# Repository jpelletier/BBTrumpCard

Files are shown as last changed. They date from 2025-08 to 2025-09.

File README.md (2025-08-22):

The Big Beautiful Trump Card is a clone of Steve Ciarcia's Trump Card based on the Zilog Z8001 CPU.
The project is released under OSHW.

To simplify the project, I use more recent components such as a CPLD to contain the glue logic and a memory chip to replace the dynamic memory.
The project is in the prototype stage for now. The PCB is at version 1, but untested yet.

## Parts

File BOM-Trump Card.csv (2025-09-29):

Reference | Value | Qty | MPN | PACKAGE | SUPPLIER | Description | Manufacturer | Supplier2 Part Number | Supplier Part Number | SUPPLIER2
C1,C4,C7,C10,C13 | 1µF | 5 |  | 0805 |  | Unpolarized capacitor
C2,C3,C5,C6,C8,C9,C11,C12,C14,C15,C16,C17,C19,C20,C22,C23 | 100nF | 16 |  | 0603 |  | Unpolarized capacitor
C18,C21,C24 | 10µF | 3 |  | 0805 |  | Unpolarized capacitor
J1 | Conn_02x05_Odd_Even | 1 |  |  | Digikey, AliExpress, eBay | Generic connector, double row, 02x05, odd/even pin numbering scheme (row 1 odd numbers, row 2 even numbers), script generated (kicad-library-utils/schlib/autogen/connector/)
R1,R2,R3,R4,R5,R6,R7,R8,R9,R10,R11,R12,R13,R14,R15,R16,R17,R18,R19,R20,R21,R22,R23,R24,R26,R27,R28,R29,R30,R31,R32,R33 | 10k | 32 |  | 0603 |  | Resistor, US symbol
R25 | 22 | 1 |  | 0603 |  | Resistor, US symbol
U1 | Z8001P | 1 |  | DIP-48 | eBay | CPU
U2 | CY62157ELL-45ZSXI | 1 |  | TSOP-II-44 | Digikey |  | Infineon | 2767919 | 448-CY62157ELL-45ZSXI-ND | Farnell UK
U3 | EPM7128STC100-15 | 1 | EPM7128STC100-15 | 1100-TQFP | AliExpress, eBay |  | Altera/Intel
U4 | 6116 | 1 |  | DIP-24 | eBay, AliExpress
U5,U6 | 74LS373 | 2 |  | DIP-20 | Digikey, AliExpress, eBay | 8-bit Latch, 3-state outputs
U7,U8 | 2716 | 2 |  | DIP-24 | -- valeurs mixées --
U9 | Z8581 | 1 |  | DIP-18 | AliExpress, eBay
U12,U13 | 74LS245 | 2 |  | DIP-20 | Digikey, AliExpress, eBay | Octal BUS Transceivers, 3-State outputs
Y1 | 12 MHz | 1 |  | HC49-U | Digikey, AliExpress | Two pin crystal

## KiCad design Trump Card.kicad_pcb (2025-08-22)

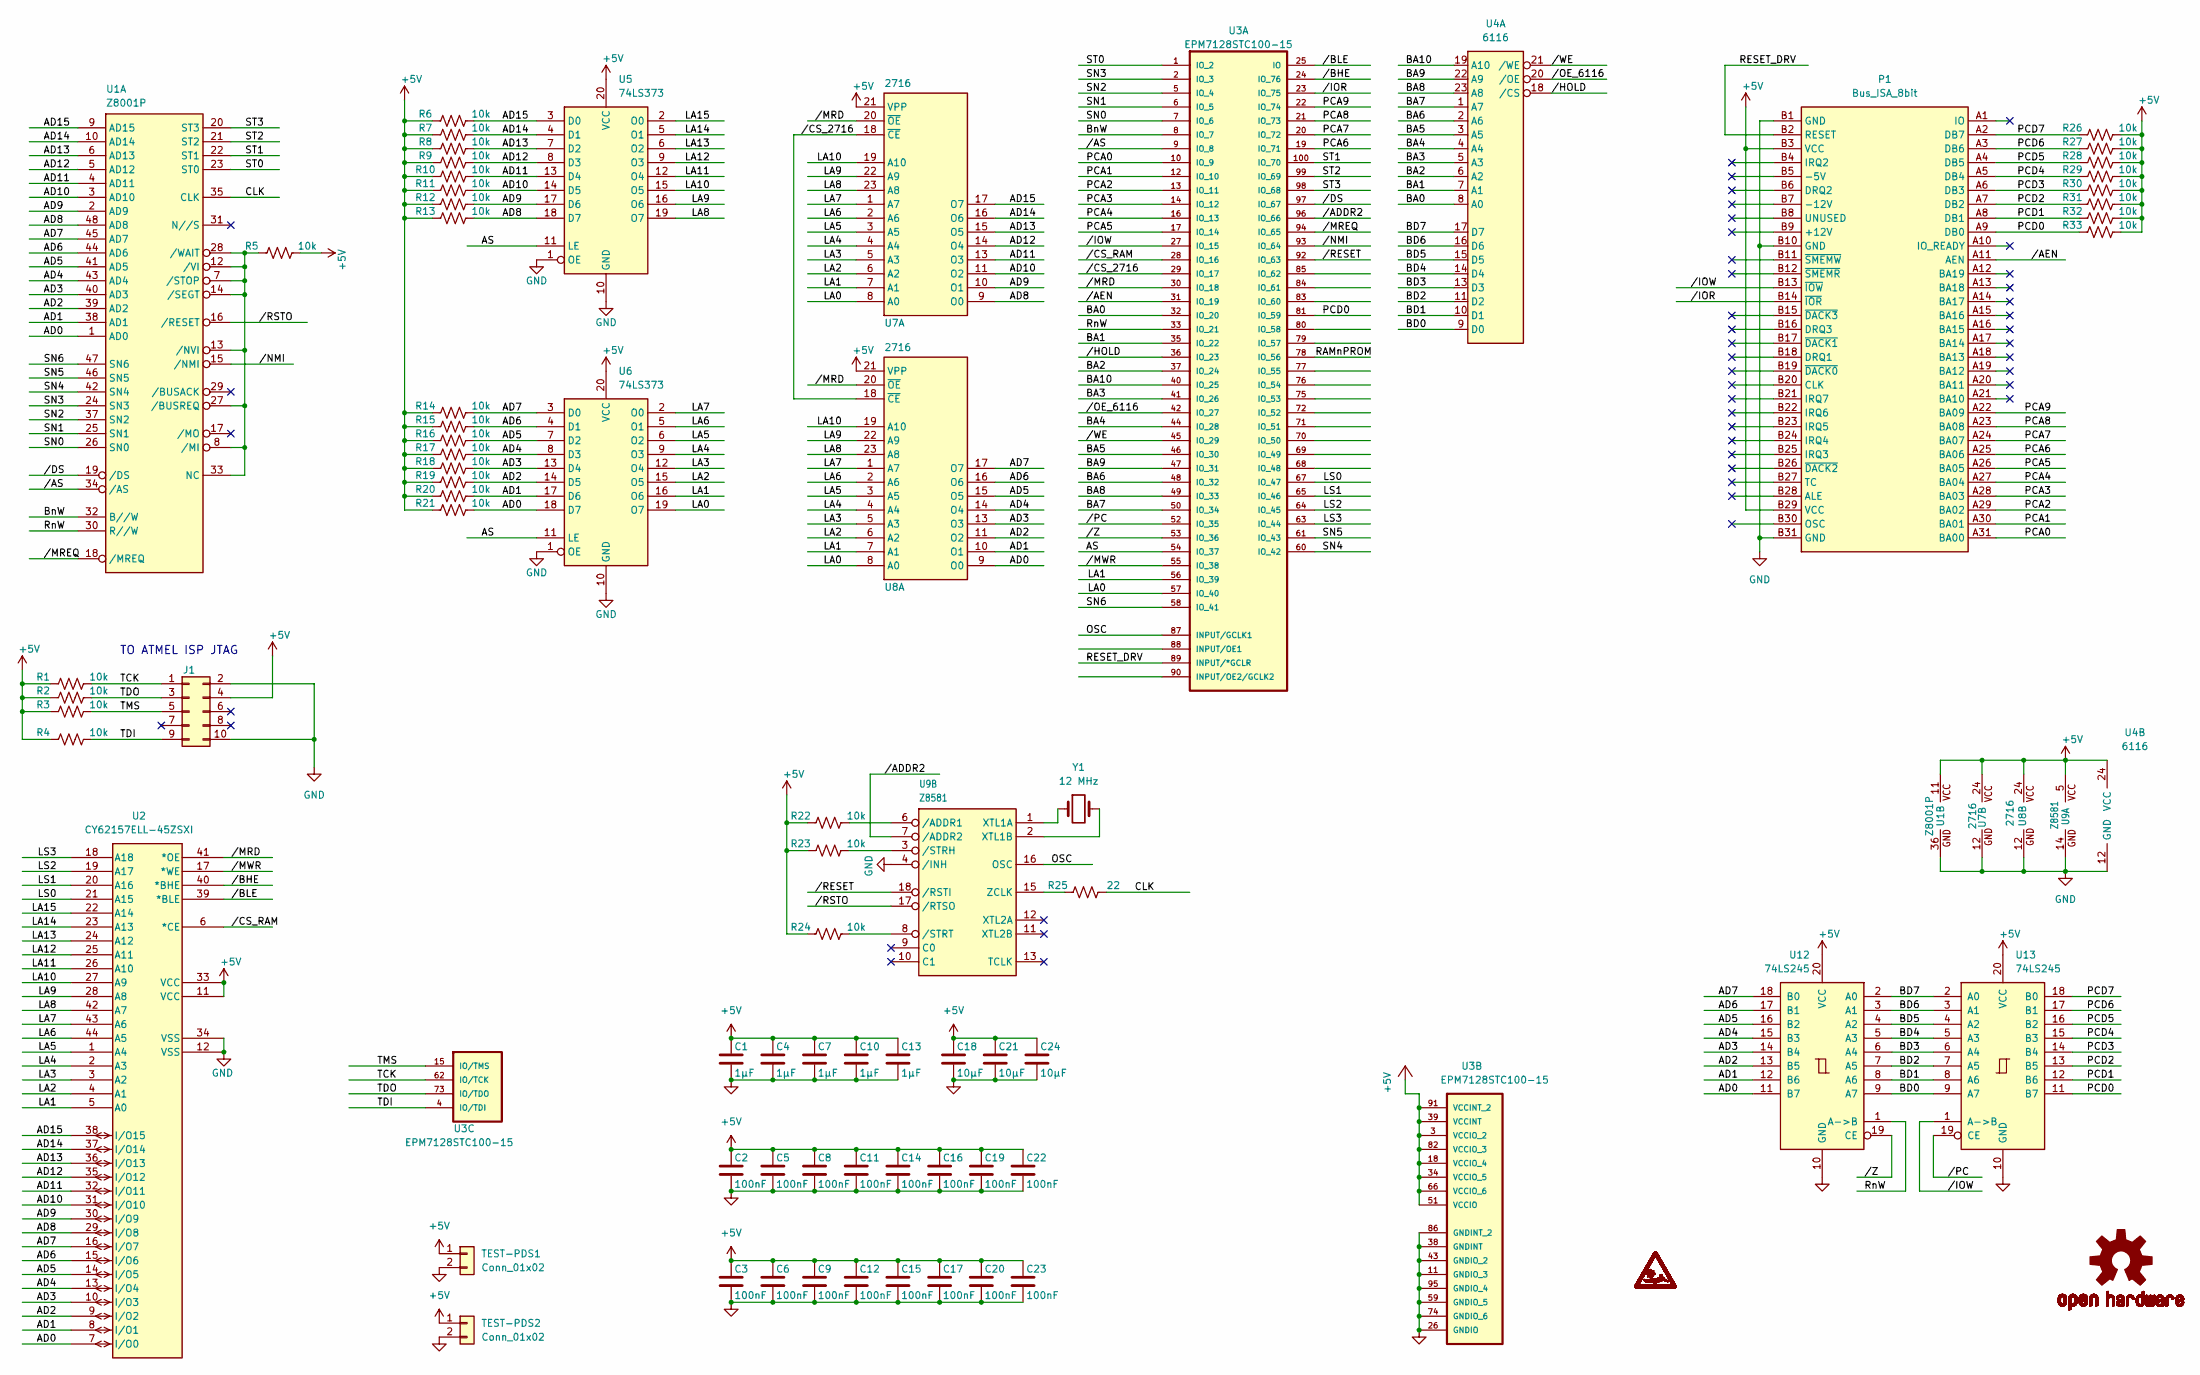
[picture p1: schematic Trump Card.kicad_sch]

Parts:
C1, C4, C7, C10, C13: 1µF; C_0805_2012Metric_Pad1.18x1.45mm_HandSolder
C2, C3, C5, C6, C8, C9, C11, C12, C14, C15, C16, C17, C19, C20, C22, C23: 100nF; C_0603_1608Metric_Pad1.08x0.95mm_HandSolder
C18, C21, C24: 10µF; C_0805_2012Metric_Pad1.18x1.45mm_HandSolder
J1: Conn_02x05_Odd_Even; PinHeader_2x05_P2.54mm_Vertical
LOGO1: OSHW-LOGOM; OSHW-LOGO-M
P1: Bus_ISA_8bit; PC-XT-Short-6in
R1, R2, R3, R4, R5, R6, R7, R8, R9, R10, R11, R12, R13, R14, R15, R16, R17, R18, R19, R20, R21, R22, R23, R24, R26, R27, R28, R29, R30, R31, R32, R33: 10k; R_0603_1608Metric_Pad0.98x0.95mm_HandSolder
R25: 22; R_0603_1608Metric_Pad0.98x0.95mm_HandSolder
TEST-PDS1, TEST-PDS2: Conn_01x02; TEST_PDS
U1: Z8001P; DIP-48_W15.24mm
U2: CY62157ELL-45ZSXI; TSOP-II-44_10.16x18.41mm_P0.8mm
U3: EPM7128STC100-15; QFP50P1600X1600X120-100N; MPN EPM7128STC100-15
U4: 6116; DIP-24_18.0mmx34.29mm_W15.24mm
U5, U6: 74LS373; DIP-20_W7.62mm
U7, U8: 2716; DIP-24_18.0mmx34.29mm_W15.24mm
U9: Z8581; DIP-18_W7.62mm
U11: PHYSNOCT_PHYSNOCT; PHYSNOCT
U12, U13: 74LS245; DIP-20_W7.62mm
Y1: 12 MHz; Crystal_HC49-U_Vertical

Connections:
+5V: C1.1, C2.1, C3.1, C4.1, C5.1, C6.1, C7.1, C8.1, C9.1, C10.1, C11.1, C12.1, C13.1, C14.1, C15.1, C16.1, C17.1, C18.1, C19.1, C20.1, C21.1, C22.1, C23.1, C24.1, J1.4, P1.B3 (VCC), P1.B29 (VCC), R1.1, R2.1, R3.1, R4.1, R5.2, R6.1, R7.1, R8.1, R9.1, R10.1, R11.1, R12.1, R13.1, R14.1, R15.1, R16.1, R17.1, R18.1, R19.1, R20.1, R21.1, R22.1, R23.1, R24.1, R26.2, R27.2, R28.2, R29.2, R30.2, R31.2, R32.2, R33.2, TEST-PDS1.1, TEST-PDS2.1, U1.11 (VCC), U2.11 (VCC), U2.33 (VCC), U3.3 (VCCIO_2), U3.18 (VCCIO_4), U3.34 (VCCIO_5), U3.39 (VCCINT), U3.51 (VCCIO), U3.66 (VCCIO_6), U3.82 (VCCIO_3), U3.91 (VCCINT_2), U4.24 (VCC), U5.20 (VCC), U6.20 (VCC), U7.21 (VPP), U7.24 (VCC), U8.21 (VPP), U8.24 (VCC), U9.5 (VCC), U12.20 (VCC), U13.20 (VCC)
/AD0: R21.2, U1.1 (AD0), U2.7 (I/O0), U6.18 (D7), U8.9 (O0), U12.11 (B7)
/AD1: R20.2, U1.38 (AD1), U2.8 (I/O1), U6.17 (D6), U8.10 (O1), U12.12 (B6)
/AD2: R19.2, U1.39 (AD2), U2.9 (I/O2), U6.14 (D5), U8.11 (O2), U12.13 (B5)
/AD3: R18.2, U1.40 (AD3), U2.10 (I/O3), U6.13 (D4), U8.13 (O3), U12.14 (B4)
/AD4: R17.2, U1.43 (AD4), U2.13 (I/O4), U6.8 (D3), U8.14 (O4), U12.15 (B3)
/AD5: R16.2, U1.41 (AD5), U2.14 (I/O5), U6.7 (D2), U8.15 (O5), U12.16 (B2)
/AD6: R15.2, U1.44 (AD6), U2.15 (I/O6), U6.4 (D1), U8.16 (O6), U12.17 (B1)
/AD7: R14.2, U1.45 (AD7), U2.16 (I/O7), U6.3 (D0), U8.17 (O7), U12.18 (B0)
/AD8: R13.2, U1.48 (AD8), U2.29 (I/O8), U5.18 (D7), U7.9 (O0)
/AD9: R12.2, U1.2 (AD9), U2.30 (I/O9), U5.17 (D6), U7.10 (O1)
/AD10: R11.2, U1.3 (AD10), U2.31 (I/O10), U5.14 (D5), U7.11 (O2)
/AD11: R10.2, U1.4 (AD11), U2.32 (I/O11), U5.13 (D4), U7.13 (O3)
/AD12: R9.2, U1.5 (AD12), U2.35 (I/O12), U5.8 (D3), U7.14 (O4)
/AD13: R8.2, U1.6 (AD13), U2.36 (I/O13), U5.7 (D2), U7.15 (O5)
/AD14: R7.2, U1.10 (AD14), U2.37 (I/O14), U5.4 (D1), U7.16 (O6)
/AD15: R6.2, U1.9 (AD15), U2.38 (I/O15), U5.3 (D0), U7.17 (O7)
/AS: U3.54 (IO_37), U5.11 (LE), U6.11 (LE)
/BA0: U3.32 (IO_20), U4.8 (A0)
/BA1: U3.35 (IO_22), U4.7 (A1)
/BA2: U3.37 (IO_24), U4.6 (A2)
/BA3: U3.41 (IO_26), U4.5 (A3)
/BA4: U3.44 (IO_28), U4.4 (A4)
/BA5: U3.46 (IO_30), U4.3 (A5)
/BA6: U3.48 (IO_32), U4.2 (A6)
/BA7: U3.50 (IO_34), U4.1 (A7)
/BA8: U3.49 (IO_33), U4.23 (A8)
/BA9: U3.47 (IO_31), U4.22 (A9)
/BA10: U3.40 (IO_25), U4.19 (A10)
/BD0: U4.9 (D0), U12.9 (A7), U13.9 (A7)
/BD1: U4.10 (D1), U12.8 (A6), U13.8 (A6)
/BD2: U4.11 (D2), U12.7 (A5), U13.7 (A5)
/BD3: U4.13 (D3), U12.6 (A4), U13.6 (A4)
/BD4: U4.14 (D4), U12.5 (A3), U13.5 (A3)
/BD5: U4.15 (D5), U12.4 (A2), U13.4 (A2)
/BD6: U4.16 (D6), U12.3 (A1), U13.3 (A1)
/BD7: U4.17 (D7), U12.2 (A0), U13.2 (A0)
/BnW: U1.32 (B//W), U3.8 (IO_7)
/CLK: R25.2, U1.35 (CLK)
/LA0: U3.57 (IO_40), U6.19 (O7), U7.8 (A0), U8.8 (A0)
/LA1: U2.5 (A0), U3.56 (IO_39), U6.16 (O6), U7.7 (A1), U8.7 (A1)
/LA2: U2.4 (A1), U6.15 (O5), U7.6 (A2), U8.6 (A2)
/LA3: U2.3 (A2), U6.12 (O4), U7.5 (A3), U8.5 (A3)
/LA4: U2.2 (A3), U6.9 (O3), U7.4 (A4), U8.4 (A4)
/LA5: U2.1 (A4), U6.6 (O2), U7.3 (A5), U8.3 (A5)
/LA6: U2.44 (A5), U6.5 (O1), U7.2 (A6), U8.2 (A6)
/LA7: U2.43 (A6), U6.2 (O0), U7.1 (A7), U8.1 (A7)
/LA8: U2.42 (A7), U5.19 (O7), U7.23 (A8), U8.23 (A8)
/LA9: U2.28 (A8), U5.16 (O6), U7.22 (A9), U8.22 (A9)
/LA10: U2.27 (A9), U5.15 (O5), U7.19 (A10), U8.19 (A10)
/LA11: U2.26 (A10), U5.12 (O4)
/LA12: U2.25 (A11), U5.9 (O3)
/LA13: U2.24 (A12), U5.6 (O2)
/LA14: U2.23 (A13), U5.5 (O1)
/LA15: U2.22 (A14), U5.2 (O0)
/LS0: U2.21 (A15), U3.67 (IO_47)
/LS1: U2.20 (A16), U3.65 (IO_46)
/LS2: U2.19 (A17), U3.64 (IO_45)
/LS3: U2.18 (A18), U3.63 (IO_44)
/OSC: U3.87 (INPUT/GCLK1), U9.16 (OSC)
/PCA0: P1.A31 (BA00), U3.10 (IO_9)
/PCA1: P1.A30 (BA01), U3.12 (IO_10)
/PCA2: P1.A29 (BA02), U3.13 (IO_11)
/PCA3: P1.A28 (BA03), U3.14 (IO_12)
/PCA4: P1.A27 (BA04), U3.16 (IO_13)
/PCA5: P1.A26 (BA05), U3.17 (IO_14)
/PCA6: P1.A25 (BA06), U3.19 (IO_71)
/PCA7: P1.A24 (BA07), U3.20 (IO_72)
/PCA8: P1.A23 (BA08), U3.21 (IO_73)
/PCA9: P1.A22 (BA09), U3.22 (IO_74)
/PCD0: P1.A9 (DB0), R33.1, U3.81 (IO_59), U13.11 (B7)
/PCD1: P1.A8 (DB1), R32.1, U13.12 (B6)
/PCD2: P1.A7 (DB2), R31.1, U13.13 (B5)
/PCD3: P1.A6 (DB3), R30.1, U13.14 (B4)
/PCD4: P1.A5 (DB4), R29.1, U13.15 (B3)
/PCD5: P1.A4 (DB5), R28.1, U13.16 (B2)
/PCD6: P1.A3 (DB6), R27.1, U13.17 (B1)
/PCD7: P1.A2 (DB7), R26.1, U13.18 (B0)
/RAMnPROM: U3.78 (IO_56)
/RESET_DRV: P1.B2 (RESET), U3.89 (INPUT/*GCLR)
/RnW: U1.30 (R//W), U3.33 (IO_21), U12.1 (A->B)
/SN0: U1.26 (SN0), U3.7 (IO_6)
/SN1: U1.25 (SN1), U3.6 (IO_5)
/SN2: U1.37 (SN2), U3.5 (IO_4)
/SN3: U1.24 (SN3), U3.2 (IO_3)
/SN4: U1.42 (SN4), U3.60 (IO_42)
/SN5: U1.46 (SN5), U3.61 (IO_43)
/SN6: U1.47 (SN6), U3.58 (IO_41)
/ST0: U1.23 (ST0), U3.1 (IO_2)
/ST1: U1.22 (ST1), U3.100 (IO_70)
/ST2: U1.21 (ST2), U3.99 (IO_69)
/ST3: U1.20 (ST3), U3.98 (IO_68)
/TCK: J1.1, R1.2, U3.62 (IO/TCK)
/TDI: J1.9, R4.2, U3.4 (IO/TDI)
/TDO: J1.3, R2.2, U3.73 (IO/TDO)
/TMS: J1.5, R3.2, U3.15 (IO/TMS)
//ADDR2: U3.96 (IO_66), U9.7 (/ADDR2)
//AEN: P1.A11 (AEN), U3.31 (IO_19)
//AS: U1.34 (/AS), U3.9 (IO_8)
//BHE: U2.40 (*BHE), U3.24 (IO_76)
//BLE: U2.39 (*BLE), U3.25 (IO)
//CS_2716: U3.29 (IO_17), U7.18 (~CE), U8.18 (~CE)
//CS_RAM: U2.6 (*CE), U3.28 (IO_16)
//DS: U1.19 (/DS), U3.97 (IO_67)
//HOLD: U3.36 (IO_23), U4.18 (/CS)
//IOR: P1.B14 (~IOR), U3.23 (IO_75)
//IOW: P1.B13 (~IOW), U3.27 (IO_15), U13.1 (A->B)
//MRD: U2.41 (*OE), U3.30 (IO_18), U7.20 (~OE), U8.20 (~OE)
//MREQ: U1.18 (/MREQ), U3.94 (IO_65)
//MWR: U2.17 (*WE), U3.55 (IO_38)
//NMI: U1.15 (/NMI), U3.93 (IO_64)
//OE_6116: U3.42 (IO_27), U4.20 (/OE)
//PC: U3.52 (IO_35), U13.19 (CE)
//RESET: U3.92 (IO_63), U9.18 (/RSTI)
//RSTO: U1.16 (/RESET), U9.17 (/RTSO)
//WE: U3.45 (IO_29), U4.21 (/WE)
//Z: U3.53 (IO_36), U12.19 (CE)
GND: C1.2, C2.2, C3.2, C4.2, C5.2, C6.2, C7.2, C8.2, C9.2, C10.2, C11.2, C12.2, C13.2, C14.2, C15.2, C16.2, C17.2, C18.2, C19.2, C20.2, C21.2, C22.2, C23.2, C24.2, J1.2, J1.10, P1.B1 (GND), P1.B10 (GND), P1.B31 (GND), TEST-PDS1.2, TEST-PDS2.2, U1.36 (GND), U2.12 (VSS), U2.34 (VSS), U3.11 (GNDIO_3), U3.26 (GNDIO), U3.38 (GNDINT), U3.43 (GNDIO_2), U3.59 (GNDIO_5), U3.74 (GNDIO_6), U3.86 (GNDINT_2), U3.95 (GNDIO_4), U4.12 (GND), U5.1 (OE), U5.10 (GND), U6.1 (OE), U6.10 (GND), U7.12 (GND), U8.12 (GND), U9.4 (/INH), U9.14 (GND), U12.10 (GND), U13.10 (GND)
unnamed: R5.1, U1.7 (/STOP), U1.8 (/MI), U1.12 (/VI), U1.13 (/NVI), U1.14 (/SEGT), U1.27 (/BUSREQ), U1.28 (/WAIT), U1.33 (NC)
unnamed: U9.1 (XTL1A), Y1.1
unnamed: U9.2 (XTL1B), Y1.2
unnamed: R25.1, U9.15 (ZCLK)
unnamed: R22.2, U9.6 (/ADDR1)
unnamed: R23.2, U9.3 (/STRH)
unnamed: R24.2, U9.8 (/STRT)

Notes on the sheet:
TO ATMEL ISP JTAG

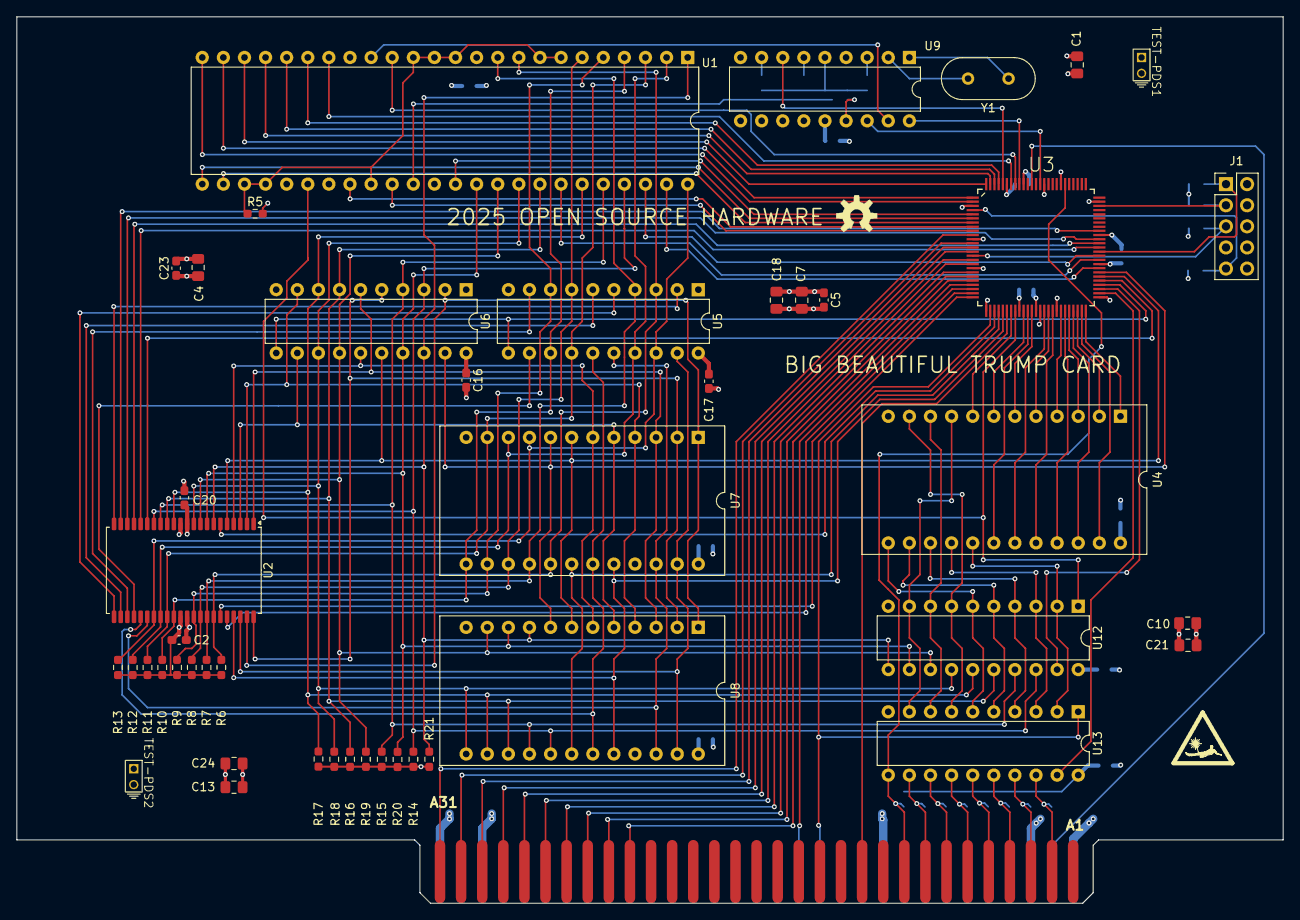
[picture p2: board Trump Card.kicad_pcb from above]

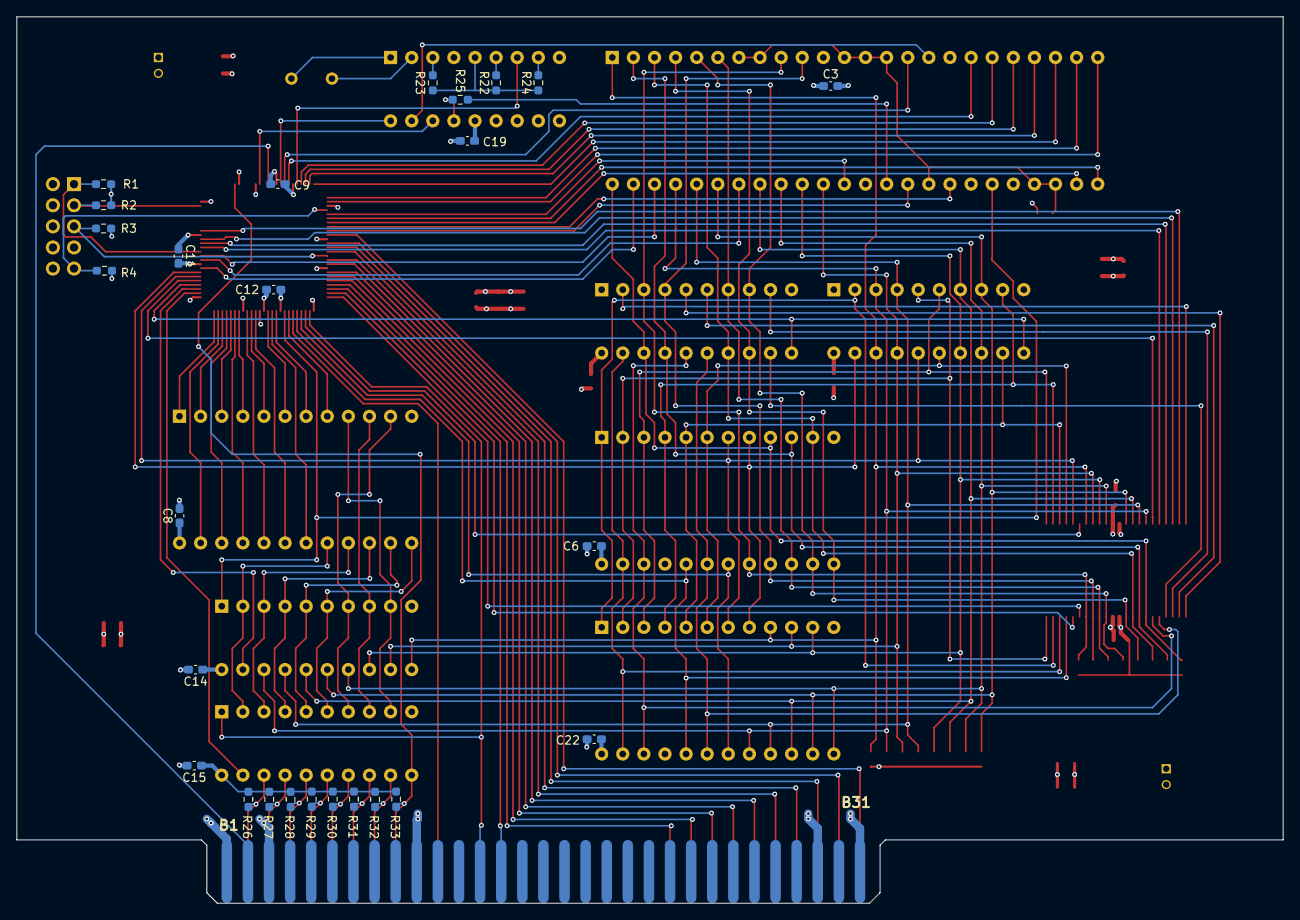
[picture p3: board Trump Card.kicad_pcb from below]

Board: 4 copper layers, 152.4 x 106.7 mm, 75 parts (26 on the bottom side), 124 nets.

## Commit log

2025-08-16 Initial commit
    This project is a clone of the Steve Ciarcia's Trump Card. I nick named it the Big Beautiful Trump Card!
    [Trump Card.kicad_sch]
2025-08-18 Changed CPLD to a EPM7128STC100-15
    The new CPLD has more available pins than the Atmel chip, and the programmer is more common and cheaper.
    [Trump Card.kicad_sch]
2025-08-22 Final commit for V1
    Modified the schematic and CPLD assignation to make PCB routing easier,
    PCB completed and gerber files provided.
    [Trump Card.kicad_pcb, Trump Card.kicad_sch]
2025-09-29 Add files via upload
    Updates on component fields to generate BOM
    [BOM-Trump Card.csv, BOM-Trump Card.ods, Trump Card.kicad_sch]
